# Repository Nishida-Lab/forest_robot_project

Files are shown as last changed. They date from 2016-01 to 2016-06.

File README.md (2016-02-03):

# Welcome to the forest_robot_project ! 

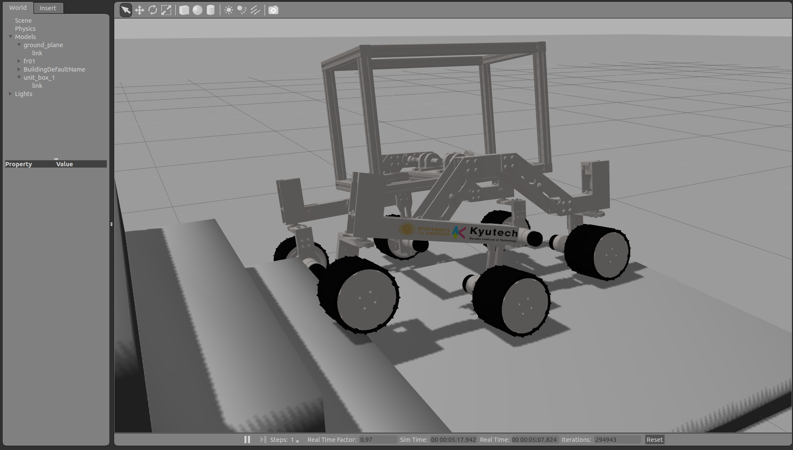
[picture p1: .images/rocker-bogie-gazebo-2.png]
fr01_gazebo


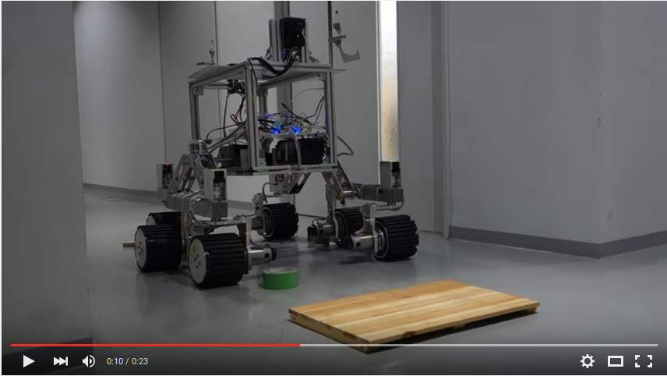
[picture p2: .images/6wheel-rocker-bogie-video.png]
fr01_real_machine (https://www.youtube.com/watch?v=MN6KCJ4qRo4)


### About
This is the repository for the forest robot (named FR01).  
**FR01** is created by [Nishida-Lab](http://lab.cntl.kyutech.ac.jp/~nishida/index.html) and [Ivan-Lab](https://www.ingegneria.unisalento.it/scheda_docente/-/people/ivan.giannoccaro).  
It has rocker-bogie mecanism. Basecally, We use [ROS](http://www.ros.org/) for control and integration.

### First of all
On this repository, there are some rules for developping.  
Please See [Issue #1](https://github.com/Nishida-Lab/forest_robot_project/issues/1) before starting.

### Install
See [Install wiki](https://github.com/Nishida-Lab/forest_robot_project/wiki/Installation-%5BEnglish%5D).

### Usage
See [Usage wiki](https://github.com/Nishida-Lab/forest_robot_project/wiki/Usage-%5BEnglish%5D).

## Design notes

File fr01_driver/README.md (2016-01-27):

# FR01(Forest Robot 01) driver

This package contains follow two nodes. 
- fr01_driver_node
- fr01_wheel_controller(not yet)

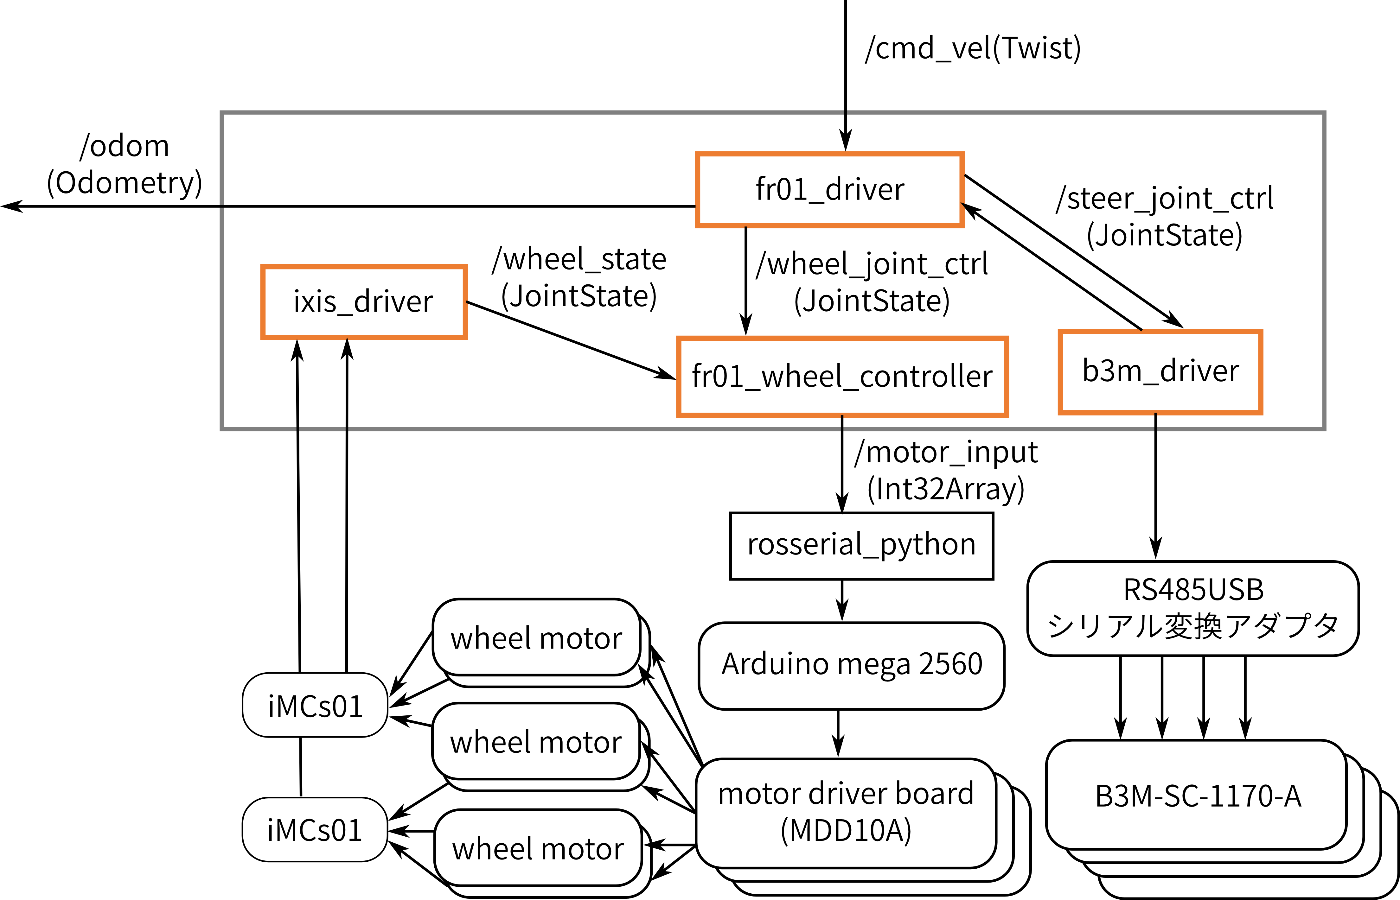
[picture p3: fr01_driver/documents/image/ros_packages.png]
ros_package
 

## fr01_driver_node
* subscribe
  - /cmd_vel
  - /wheel_state
  - /steer_state

* publish
  - /wheel_joint_ctrl
  - /steer_joint_ctrl
  - /odom

## fr01_wheel_controller_node
* subscribe
  - /wheel_state
  - /wheel_joint_ctrl

* publish
  - /motor_input(topic name is undecided)

## Preparation
In order to run this package, we need follow packages.
Please clone these packages manually or use wstool.

* [ros_ixis_imcs01_driver_beta](https://github.com/AriYu/ros_ixis_imcs01_driver_beta)
* [ros-kondo-b3m-driver-beta](https://github.com/AriYu/ros-kondo-b3m-driver-beta)

## How to run
Not yet.

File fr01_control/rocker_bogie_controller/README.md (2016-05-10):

## Rocker Bogie Controller ##

Controller for a rocker bogie drive mobile base.

Detailed user documentation can be found in the controller's [forest_robot_project wiki page](https://github.com/Nishida-Lab/forest_robot_project/wiki/rocker_bogie_controller).

- 左方向
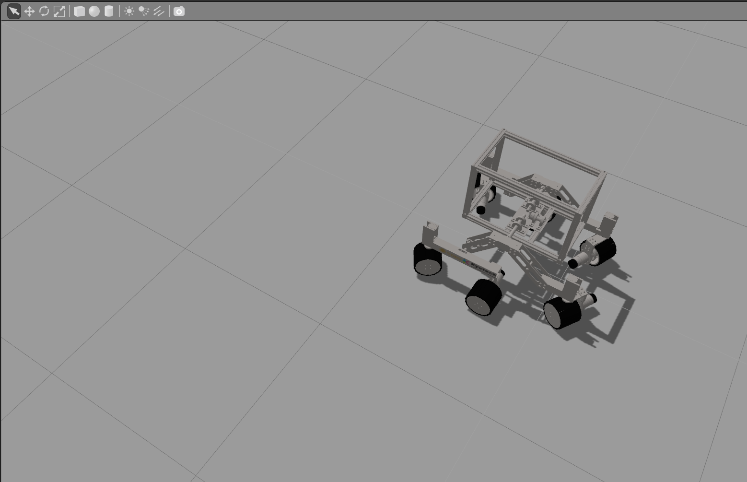
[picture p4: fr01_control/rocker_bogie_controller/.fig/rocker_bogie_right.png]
左方向


- 右方向
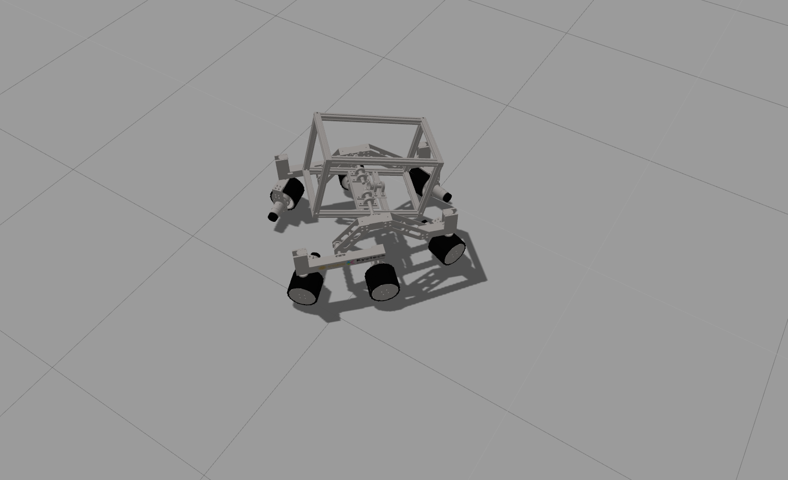
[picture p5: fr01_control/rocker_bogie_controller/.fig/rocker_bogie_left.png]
右方向


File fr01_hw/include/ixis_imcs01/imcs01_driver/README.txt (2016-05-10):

Linux kernel 3.2 用 iMCs01 USB ドライバ 2012年9月14日版
株式会社イクシスリサーチ

***ファイルについて***

Linux kernel 2.6 用 iMCs01 USB ドライバソース urbtc2.6ディレクトリ には以下のファ
イルが含まれています。

-imcs01_driver
  README.txt			//現在開いているファイル
  Makefile			//サンプルプログラム用Makefile
  h8test.c
  uread.c
  urobotc_ad.c
  urobotc_open_loop.c
  urobotm.c
  urobot_1ch_enc_pos.c
  urobot_enc_pos.c
─driver
    Makefile		//ビルド用の Makefile
    urbtc.c		//ドライバの本体
    urbtc.h		//ioctl 用のヘッダ
    urobotc.h		//read/write するデータを定義するヘッダ

***ビルドおよび動作環境***

Ubuntu1204で、ビルドおよび動作確認をしています。

ビルドには、uname -r でわかる現在動作中の kernel に対応する、
kernel-devel パッケージをインストールしておく必要があります。

$ uname -r
3.2.0-29-generic-pae

となるような環境では、linux-source-3.2.0 パッケージをあらかじめインストールしておいてください。
$ sudo apt-get install linux-source-3.2.0

カーネルソースをダウンロード後、以下を実施し、必要なファイル類の解凍を行います。
$ cd /usr/src
$ sudo tar xf linux-source-3.2.0.tar.bz2

/boot以下の現在のカーネル環境の.configを取得します。
$ cd linux-source-3.2.0
$ sudo cp /boot/confing-3.2.0-30-generic-pae .config

その後、makeを実施します。
$ sudo make oldconfig
$ sudo make

***ビルド方法***

ビルドはドライバのソースを展開したディレクトリに移動し、

$ make

とします。うまくコンパイルが成功するとドライバモジュールファイル
urbtc.ko が作成されます。

適切な kernel-devel パッケージがインストールされていない場合、以下の
ように表示されて make が失敗します。

$ make
make -C /lib/modules/2.6.15-1.2054_FC5/build M=/disk/tonki/d50/proj/ixs-usb/work/mrt/urbtc-2.6 modules
make: *** /lib/modules/2.6.15-1.2054_FC5/build: No such file or directory.  Stop.
make: *** [default] Error 2

***動作確認***

kernel 2.4 用ドライバのソースに附属の、以下のプログラムについて動作
確認しています。

h8test
uread
urobot_1ch_enc_pos
urobot_enc_pos
urobotc_ad
urobotc_open_loop
urobotm

環境は Ubuntu12.04です。

手順は
$ sudo insmod urbtc.ko
としてドライバをロードしたのちに、デバイスを USB コネクタに差します。

/dev/urbtc0が作られることを確認します。
$ ls -l /dev/urbtc*

アクセス権を変更します。
$ sudo chmod 777 /dev/urbtc0

上記のプログラムを順次起動しています。

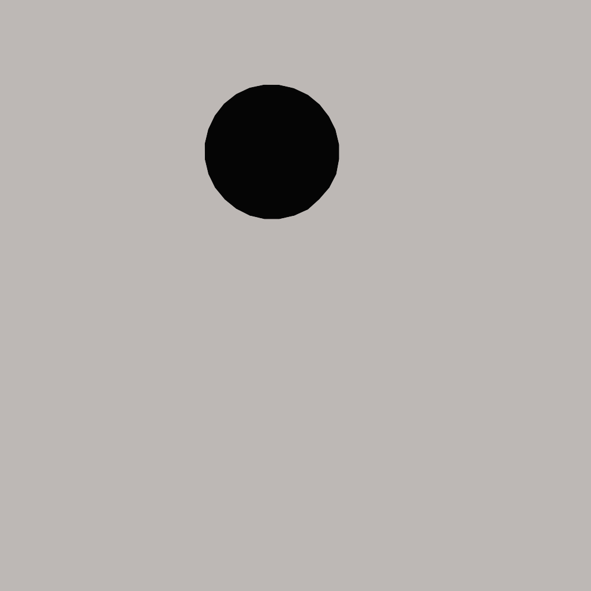
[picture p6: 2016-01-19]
fr01_description/meshes/visual/steer_link_texture.png

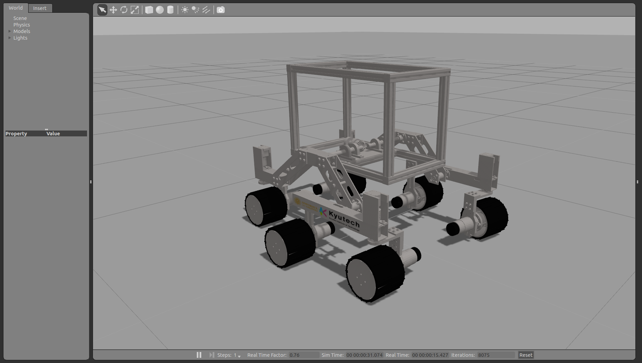
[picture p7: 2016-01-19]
.images/fr01_gazebo.png

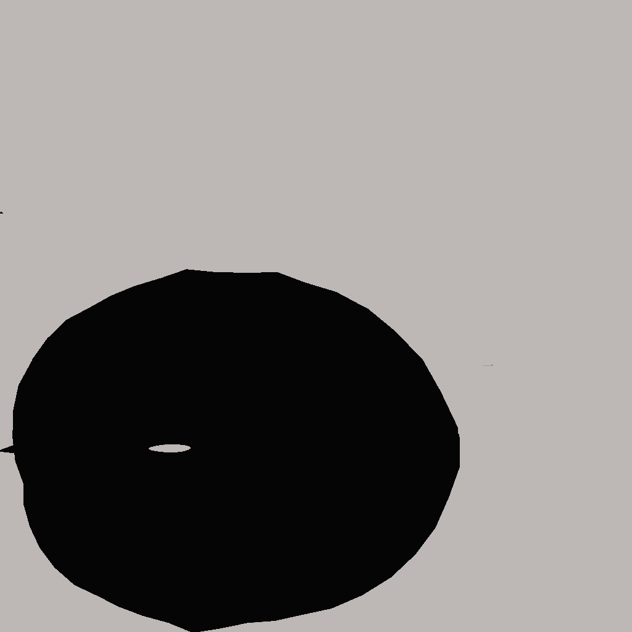
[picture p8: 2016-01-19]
fr01_description/meshes/visual/wheel_link_texture.png

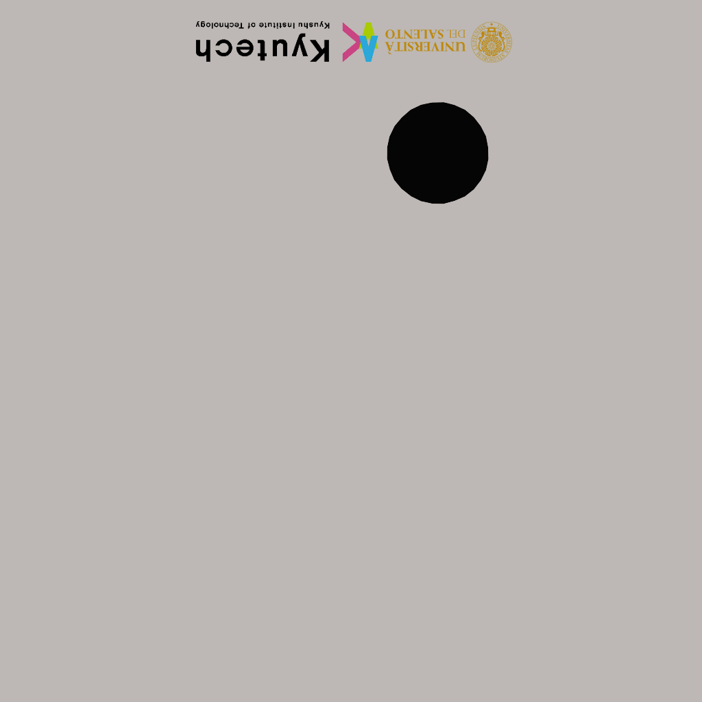
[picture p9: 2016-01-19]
fr01_description/meshes/visual/bogie_left_link_texture.png

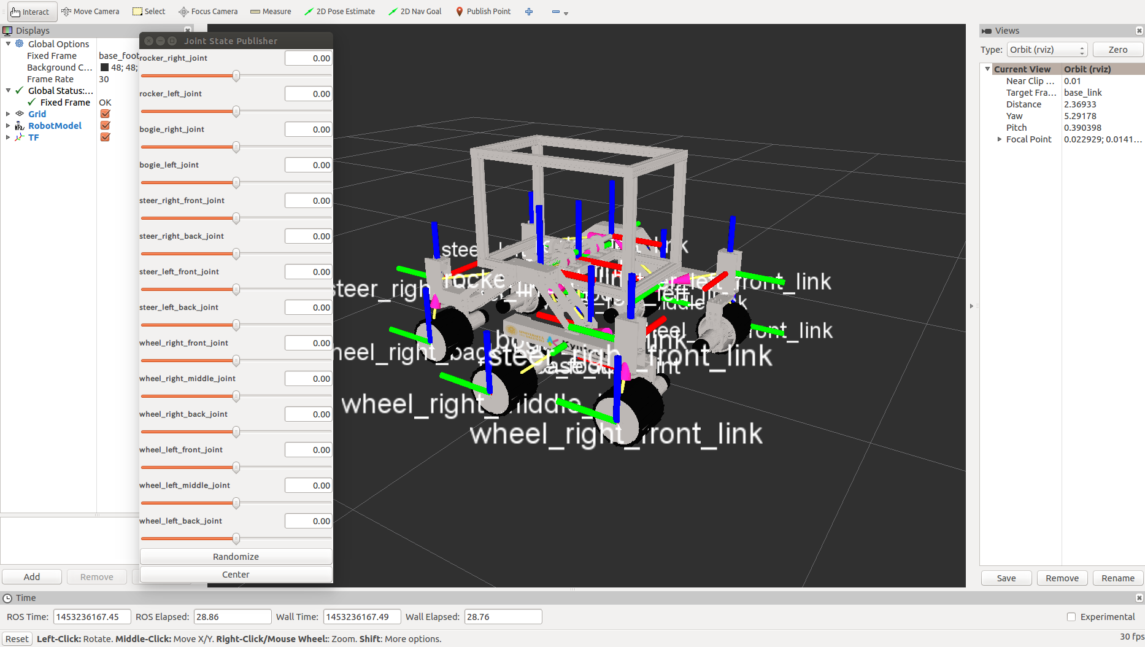
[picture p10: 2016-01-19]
.images/fr01_description_rviz.png

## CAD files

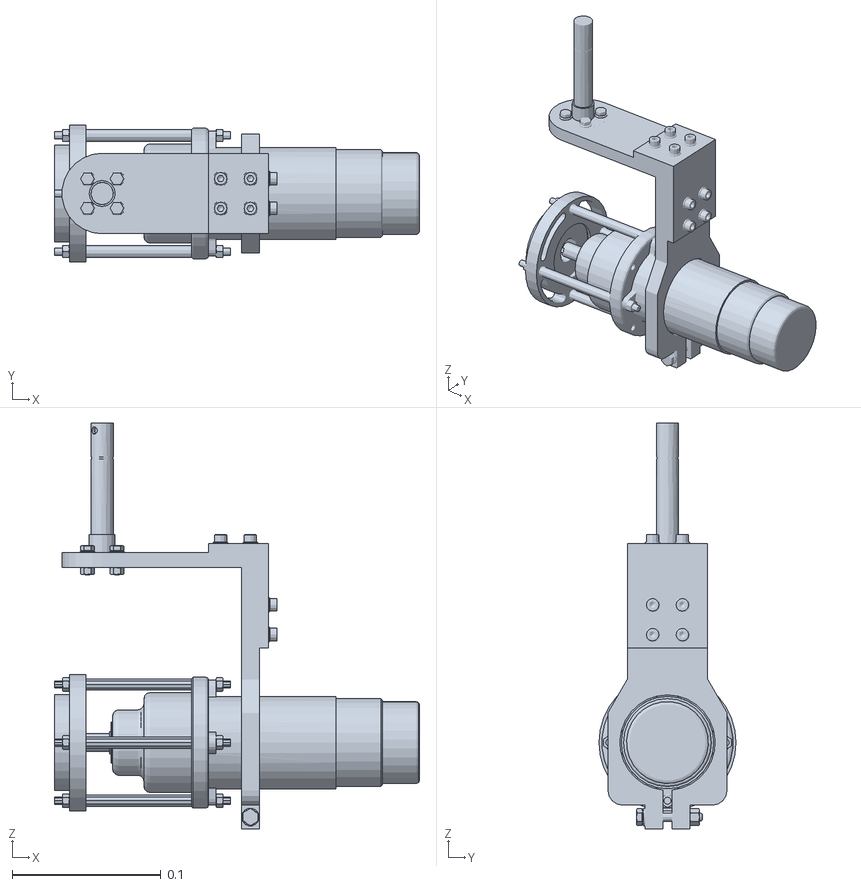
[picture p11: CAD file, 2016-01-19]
fr01_description/meshes/collision/steer_link.stl
0.245 x 0.092 x 0.273

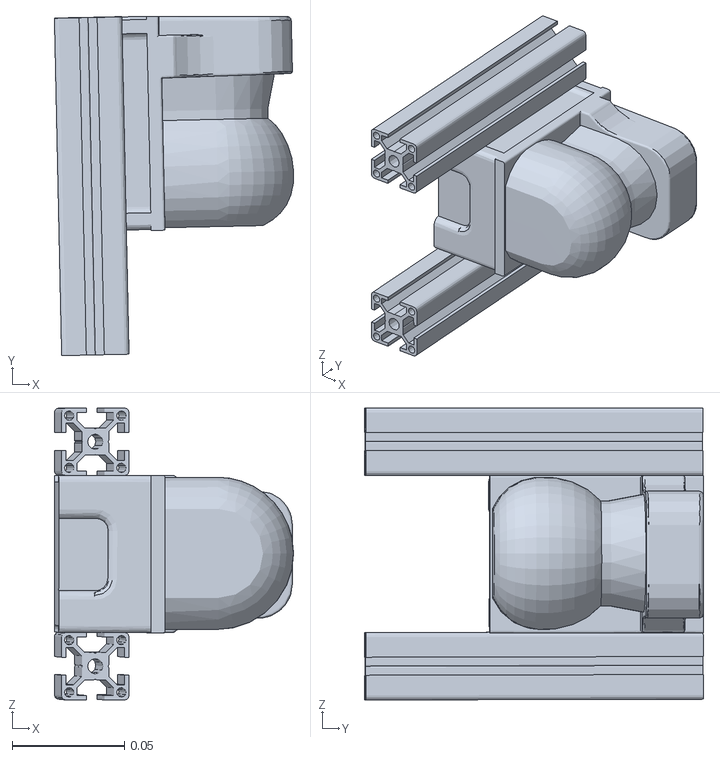
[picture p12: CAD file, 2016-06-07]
fr01_description/meshes/visual/yvt-x002.stl
0.106 x 0.151 x 0.13

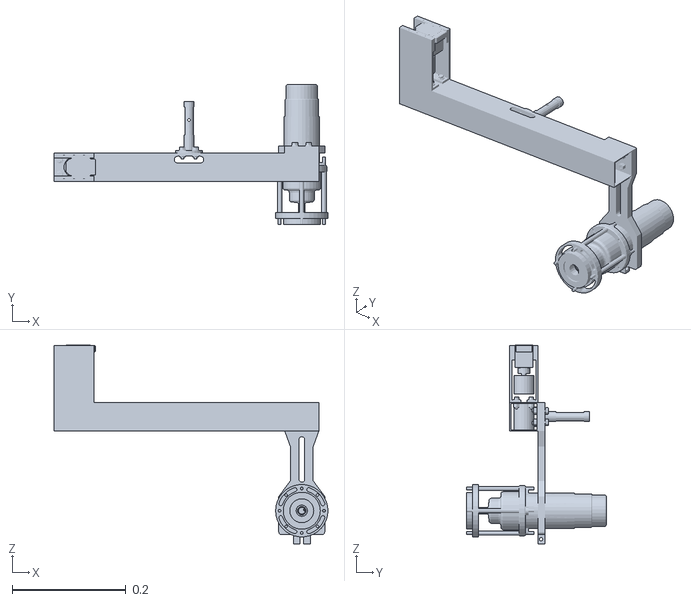
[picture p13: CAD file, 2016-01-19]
fr01_description/meshes/collision/bogie_left_link.stl
0.481 x 0.245 x 0.348

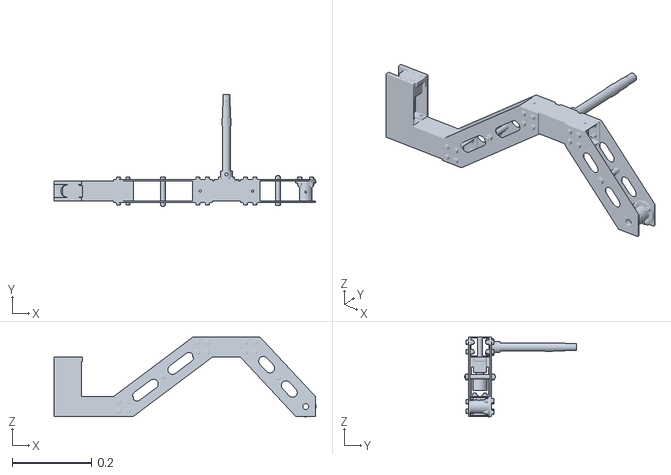
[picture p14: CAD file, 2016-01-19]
fr01_description/meshes/collision/rocker_right_link.stl
0.661 x 0.283 x 0.201

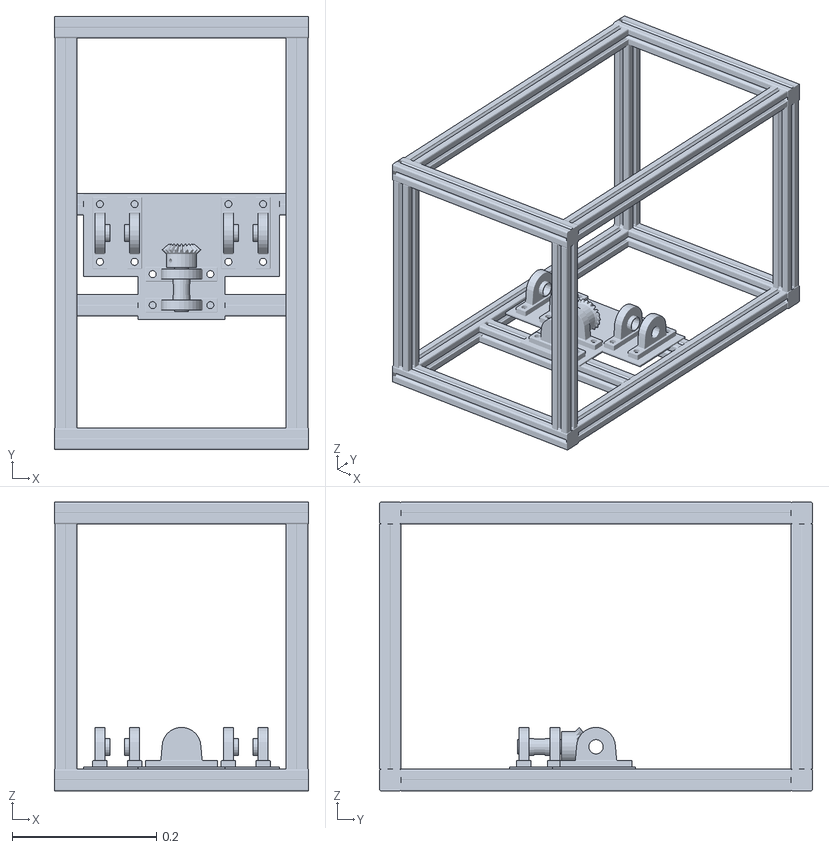
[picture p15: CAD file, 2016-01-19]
fr01_description/meshes/collision/base_link.stl
0.352 x 0.6 x 0.4

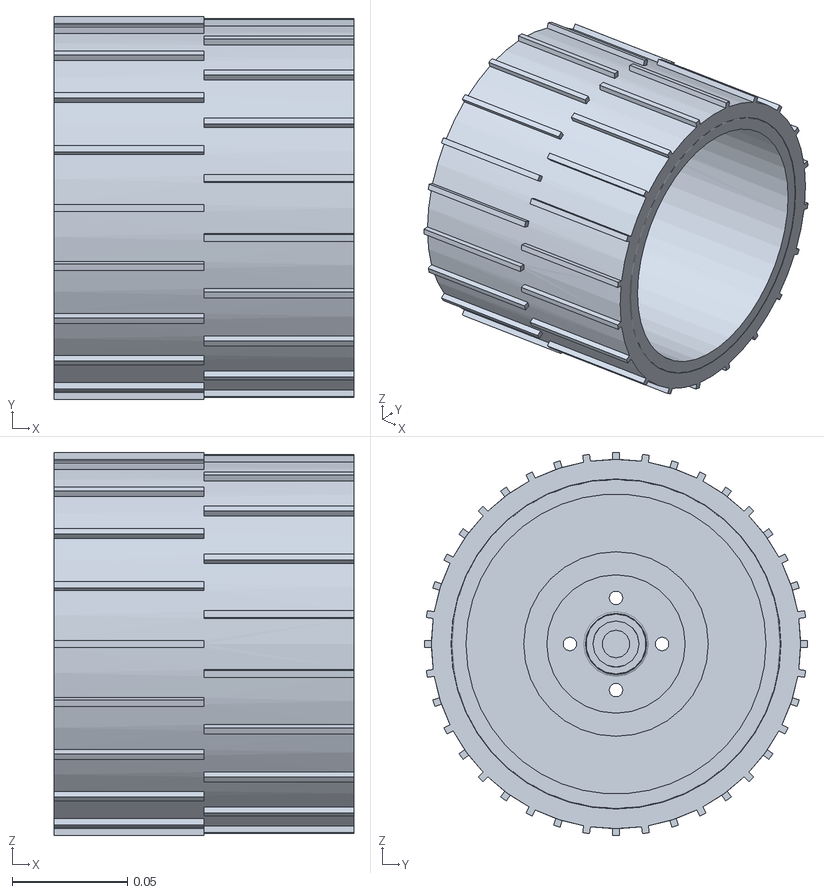
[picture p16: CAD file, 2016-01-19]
fr01_description/meshes/collision/wheel_link.stl
0.13 x 0.166 x 0.166

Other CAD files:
fr01_description/meshes/collision/rocker_left_link.stl
fr01_description/meshes/collision/bogie_right_link.stl

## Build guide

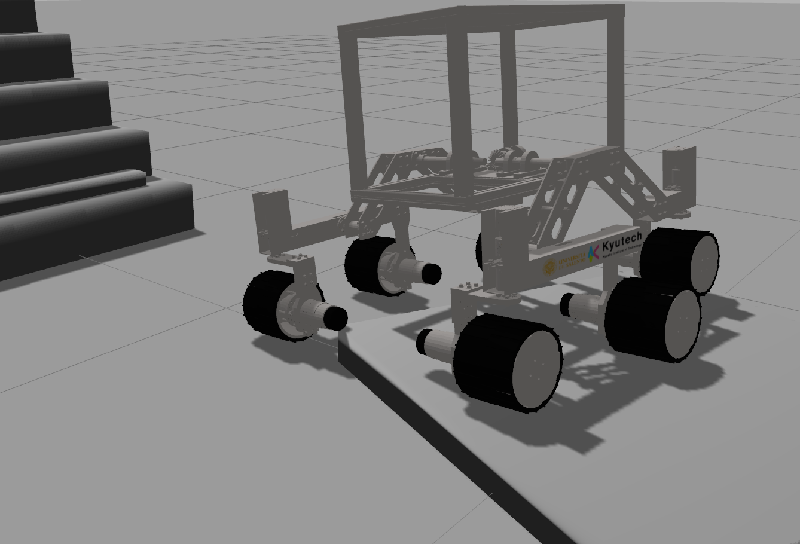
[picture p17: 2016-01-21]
.images/fr01_with_step_gazebo.png

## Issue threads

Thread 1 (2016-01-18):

About this repository

RyodoTanaka, 2016-01-18:
Nishida-Lab and Ivan-Lab members will share this repository.
So, We will set some rules.

1. If you commit and push your codes, please write the details about the modification.

2. If you have some question, ask at this issue page. Of course, in English please.

3. Please follow [GitHub-Flow](http://scottchacon.com/2011/08/31/github-flow.html) method.

Thanks for your understanding and cooperation.

P.S
Only first commit is written in Japanese. Please accept my apology....

---- From here for Japanese. ----
本リポジトリは、イタリアのサレント大学の方も閲覧するようになります。
なので、上記の通り、コミット履歴やissueなどは英語でおねがいします。
色々手間かと思いますが、何卒よろしくおねがいします。
P.S
最初のコミットだけ日本語になっています。ご容赦下さい。。。。

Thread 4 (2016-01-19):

About Gazebo Simulator

RyodoTanaka, 2016-01-19:
I already merged the codes for gazebo elements.
But there are some problems we have to resolve.
So, I want to share these info.And following info is same to #3 Pull Requests.

1. Now, steer and wheel joints are moved by joint position controller.
    We need to change this controller to velocity controller (We need to make original ros_controller).

2. Not enough at experiment. We need to experiment on steer, obstacle, and unevenness terrains.
    Of course, We need to create such terrains on Gazebo too.

3. Sometimes the calculation on Gazebo doesn't works.
    But now, I don't know the reason and solution.

That is all.
Thank you for your cooperation.

mum254, 2016-01-24:
@RyodoTanaka
> We need to change this controller to velocity controller (We need to make original ros_controller).

Do you really need to create a velocity controller from scratch?

[ros_control wiki](http://wiki.ros.org/ros_control) says the package also provides `velocity_controllers/joint_velocity_controllers` & `Joint Command Interfaces/Velocity Joint Interface`.

What about simply replacing the controller and the interface on `position` to the velocity ones?

RyodoTanaka, 2016-01-24:
@mum254
 > Do you really need to create a velocity controller from scratch?
 > ros_control wiki says the package also provides velocity_controllers/joint_velocity_controllers & Joint Command Interfaces/Velocity Joint Interface.
 > What about simply replacing the controller and the interface on Position to the Velocity ones?

Yes, Exactly. But I wanted to say that we need a velocity controller that the robot get the `cmd_vel` topic message ( that is `Twist` message I mean). So, I thought we need to calculate  the commands for each joints from  `cmd_vel` message.
And Now, we have a kinematics model and the matrix for calculation. So, I thought we need to create original controller...
Thank you for your advice and sorry for my less explanation.

mum254, 2016-01-24:
@RyodoTanaka
Ooops, excuse me. That makes sense! Surely you need original one =)

mum254, 2016-01-30:
@RyodoTanaka
May I try the controller stuff? I'm curious about both the kinematics and ros_control plugin implementation.

@luigicapodieci
I'll try to grasp basics on the paper you introduced to me =).
Let's have a discussion on my next visit (Feb.5).

RyodoTanaka, 2016-02-01:
@mum254
I'm sorry to late reply...

Sure, of course ! We need your help.
I have an interest in that and want to join your working.
Let's make it complete !!!

mum254, 2016-02-02:
@RyodoTanaka
Thanks!
Yeah. Let's make it together!

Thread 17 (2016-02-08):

About tf tree

AriYu, 2016-02-08:
I checked tf tree for adding `/odom` frame and found strange transforms like follow image.
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
I added `hokuyo3d_link` before checking tf tree.
I think `base_footprint` should be transformed from `base_link` or nearly root of tree.
Please tell me why it is, thank you.

RyodoTanaka, 2016-02-08:
@AriYu
Year, I understand your saying. And, I think It is not good (wrong) statement.
But there is a reason why I set such a strange tf tree. I'll tell you the situation.

First, I set the `base_footprint` be transformed from `base_link`.
Then, I simulated with Gazebo. And I found the `base_link` was moving. That means `base_footprint` was moving.
I thought `base_footprint` should be on the ground and not move (to Z axis direction).
So, I set these strange tf trees.

Of course I know it's not good idea, and may be I think, we don't need to do that.
But I have no idea. Please let me know your idea.

mum254, 2016-02-08:
I'm not familiar with the issue but let me give something here.

have a look at TF tree of p.310 of `Learning ROS for Robotics Programming 2nd Edition`. all related files about the tree are also available on Github including xacro of a very simple wheel robot.

hope u guys will find some hints from that.

AriYu, 2016-02-09:
@RyodoTanaka
OK, I understood.
But, why did you try to transform `base_footprint` from `base_link` ?
I read `Learning ROS for Robotics Programming 2nd Edition`,
the book say
`base_footprint` => `base_link` => `wheels`
is better.

@mum254
Thank you for your suggestion.

RyodoTanaka, 2016-02-09:
@AriYu
Sorry, I had mistake.
> First, I set the base_footprint be transformed from base_link.

That's not correct. I wanted to say
> I set the base_link be transformed from base_footprint.

I mean, I set the tree `base_footprint` -> `base_link`.
If you want to check that, go [72001a6bd18ebd8427af832ac2ffb376a0ec905f](https://github.com/Nishida-Lab/forest_robot_project/tree/72001a6bd18ebd8427af832ac2ffb376a0ec905f).
And on [the next commit (c9a5be3752d1d337ee8d7d0097c058869a3e1279)](https://github.com/Nishida-Lab/forest_robot_project/tree/c9a5be3752d1d337ee8d7d0097c058869a3e1279), I changed that to now we use.

RyodoTanaka, 2016-02-09:
@AriYu
Now, we don't use the gear on the middle of the robot. Because, we need more resource for calculation and the model would be more complex to simulate.
But, we have never tried that. And, we have another problem on the tf tree.
So now, It worth to add the gear on the simulated model I think.
Even if we need to recreate some stl files...
Please give me your opinion.

AriYu, 2016-02-09:
@RyodoTanaka
OK, I see.
For the time being, I will go under this structure of tf tree.
If we found better solution, fix this problem.
So, this issue will not close until this problem is solved.

AriYu, 2016-03-01:
In `fix-tf-tree` branch, we tried new structure of tf tree fr01.
A new structure of tf tree is like this.
`base_footprint` => `base_stabilized` => `base_link` => `other_links`
I referenced `hector_slam` tutorial. That link is [here](http://wiki.ros.org/hector_slam/Tutorials/SettingUpForYourRobot).
And, this structure looks no problems.
[fr01_modified_TF_tree.pdf](https://github.com/Nishida-Lab/forest_robot_project/files/152457/fr01_modified_TF_tree.pdf)
But, the modify will influence other programs such as using `fake_base_footprint`, because `fake_base_footprint` is deleted. Then, some other problems maybe occur.
So, I want to get your agreement.
Thank you @RyodoTanaka

Closed 2016-03-14.

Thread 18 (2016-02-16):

consultation about the implemention of  hardware_interface::RobotHW

AriYu, 2016-02-16:
I'm writing our original `hardware_interface` inheriting `hardware_interface::RobotHW` to adjust `ros_control`.
`fr01(forest robot)` has 6 wheel and 4 steer joints. And wheel is velocity control, steer is position control. But it look like that the `hardware_interface` class should be definite just only one. Then, the main function is like bellow snippet.
```
main()
{
  MyRobot robot;
  controller_manager::ControllerManager cm(&robot);

  while (true)
  {
     robot.read();
     cm.update(robot.get_time(), robot.get_period());
     robot.write();
     sleep();
  }
}
```
If we have to implement all in `read()` for all motors, the problem is `read()` require long time. Because, serial servo (B3M Kondo servo) is often mistake (invalid checksum) and we have to re-read from servo motor. In my experience, the maximum re-reading times is 4. Every reading require 5[ms].
As a result, above code snippet's loop rate maybe very slow.
How do I should do this ?

reference : https://github.com/ros-controls/ros_control/wiki/hardware_interface

mum254, 2016-02-16:
@AriYu
How do you handle the problem currently on the real robot?
I believe this is the common issue on both the current case and RobotHW case.

If `read()` method takes long time because of networking failure, it just cause that a constant command is sent to each actuators during `read()` method procedure.

In other words, a new command calculated from the newest value cannot be gained until `read()` returns.
Does this also happen in the current driver principle?

In the current driver, a command value from the newest joint position is computed when the topic `/wheel_state` is updated. Until then, a constant joint command should be sent to a motor driver.

This seems same with the procedure `cm.update()` is computed when the `read()` is finished. Until then, a constant joint command should be sent to a motor driver.

If I'm getting a mistake, please point it out. Thanks.

mum254, 2016-02-16:
I'll be in the lab on 2/17(Wed) in the morning. If you are available, please let me have a discussion on this.

AriYu, 2016-02-16:
@mum254
Sorry, I have class tomorrow morning from 8:50 until 10:20. But the other time, we can discuss. Thank you.

In the current structure of `fr01_driver`, steer control node and wheel control node is independent. So, wheel control node don't need to wait for steer control node updating. But, in `ros_control`, If we have to implement in `read()`(reading from wheel encoder and steer servo), wheel controller have to wait some times.

However , I came up with an idea just now. If we can publish some topic in `write()`, we use current node for wheel motor control. And `read()` taking long time wont be big problem.

AriYu, 2016-02-16:
@mum254
This is real robot implementation problem. Sorry, I forget to say that.

mum254, 2016-02-16:
@AriYu
ok, understood what you mean. talk about it later =-)

AriYu, 2016-02-24:
Now, ros_control for real hardware is implemented in `use_ros_control` branch.
And, almost of them are finished.
But, If you find some problem, please pull request.
The new rocker-bogie controller have developed, I will do test.

MoriKen254, 2016-02-24:
@AriYu
great! super quick job!
let me check the code & compatibility with gazebo=-)

MoriKen254, 2016-02-29:
@AriYu
Cool, I believe your code will be compatible with `ros_controller`. It's my turn to commit.

Now, let me check my understanding on your driver. Is the software configuration like the following fig? (some details are abbreviated.)
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
Please tell me a mistake if it exists.

By the way, when do you want the common `ros_controller` by? I might be short of developing time until next week. However, I wanna do my best to finish it by the deadline if you have.

AriYu, 2016-02-29:
@MoriKen254
Thanks.

I think that your understanding is right and the figure is awesome. Thank you your great works !!! Making the figure should be my work, sorry.

Please don't worry about deadline, because the interim presentation is April and the robot have moved already. Of cause, it is important to compatible with `ros_control` and I want to move the robot using `ros_control`. But it is not urgent.

Incidentally, I would like to move codes about `ros_control` to `fr01_control` directory from `fr01_driver` directory. How about this idea ?
And I want to remain `fr01_driver` directory, because `fr01_driver` is able to control real robot. However in the future, if we confirm to control the robot by using `ros_control`, I will remove it.

MoriKen254, 2016-03-01:
@AriYu
> don't worry about deadline

Ok, thanks.

>  I would like to move codes about ros_control to fr01_control directory from fr01_driver directory.

sure, I got it. I'll modify the configuration of fr01_control.

>  I want to remain fr01_driver directory

Ok, let's merge them after checking the compatibility. Thanks for your comment =-)

AriYu, 2016-03-02:
@MoriKen254
I have a question about `fr01_control` directory.
Where will I put code about `ros_control` for real hardware ?
For example
`fr01_control/src/real_hardware/some_codes_for_real_hardware.cpp`
or
`fr01_control/src/some_codes_real_hardware.cpp`
If you have any other idea, please tell me it.

MoriKen254, 2016-03-02:
@AriYu

I prefer the former one from your options.

Or how about the following one?
The main idea is to split hw space from controller one.
hw space includes real and sim hw codes, while control space includes ros_controller which is compatible with both real  and sim.

├ `fr01_control/` (ros_controller. both real and sim can use.)
│　├ `rocker_bogie_controller/`
│　│　└ src
│　│　　　└ rocker_bogie_controller.cpp
│　└ `some_another_custom_controller/`
│　　　└ src
│　　　　　└ some_another_custom_controller.cpp (not needed for now)
│
└ `fr01_hw/`
　　├ `real`
　　│　└ src/
　　│　　　├ hw_real_node.cpp
　　│　　　├ hw_real.cpp
　　│　　　└ some_codes_for_hw_real.cpp
　　└ `sim`
　　　　└ src/
　　　　　　└ codes_for_hw_sim_plugin.cpp (not needed for now)

Umm, what do you think about it? You wanna move driver codes to controller space don't you? I know your idea because `some_codes_for_hw_real` in fr01_driver also include `controller`.

In my opinion, dividing `RobotHW` and `ros_controller` seems reasonable.

If you have any idea about the issue, please let me know.

AriYu, 2016-03-03:
@MoriKen254
Thank you for your suggestion. I think your suggestion is very good.
I will try to organize directory structure following  your idea in `use_ros_control` branch.

Closed 2016-05-10.

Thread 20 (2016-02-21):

Please tell me wheel radius and width!

mum254, 2016-02-21:
As mentioned in the title. I couldn't figure them out from a collada format file lol.

## background
I'm trying to apply [diff_drive_controller](http://wiki.ros.org/diff_drive_controller) to the robot as start up.

The controller requires the radius and width of wheels, which are used to compute kinematics of the model inside and should be needed for our robot  model as well.

AriYu, 2016-02-21:
@mum254
I understood. That's great.
Wheel diameter is 0.16[m], so the radius is 0.08[m].
And width of wheels is 0.13[m].
If you want to get some other parameters, please feel free to ask anything.

mum254, 2016-02-22:
@AriYu
Thanks. I'll surely ask something again.

Closed 2016-02-22.

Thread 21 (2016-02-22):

Could you remove the namespace `fr01` from the urdf model?

mum254, 2016-02-22:
As mention in the title. If the request is accepted, I want you check all the compatibility about namespace other than the things I noted below. That's why I didn't send pull request directly.

That's because diff_drive_controller doesn't seem to support namespace so the original model with namespace doesn't response when it gets cmd_vel topic. Other robots on github using the controller don't seem to use namespace either I searched so far.

Thus firstly, I tried several approaches to keep namespace `fr01` while removing the namespace when applying diff_drive_controller. However, all of them didn't worked well to the extend I worked on.

The only and the simplest way is just removing the namespace from urdf. (To be honest, I don't wanna take looooong time to fix files to remain this namespace stuff lol.)

Then I change files as follows:

- removed `fr01` from control yaml file,
- removed `ns` property of `controller spawner` and <remap> tag of `robot_state_publisher` in fr01_sim_control.launch,
- removed <robotNamespace> tag from gazebo plugin load tag in fr01.urdf.xacro.

After that, gazebo model started to run with cmd_vel, and everything seems going well. If possible, please remove namespace like above and fix related items you guys know.

Thanks.

AriYu, 2016-02-23:
I see. It looks difficult to keep namespace `fr01`.
So, you can remove it and please pull request.
I think the gazebo model is independent other packages, so the effect is minimum. If there are some problem, I will fix it.

mum254, 2016-02-23:
@AriYu
Thanks. I'll push it later.
Let's implement the driver with a simple one at first and solve the namespace issue if another one gets needed =-)

AriYu, 2016-02-23:
@mum254
I see. Thanks.

mum254, 2016-02-23:
sent a request related on this issue. closing.

Closed 2016-02-23.

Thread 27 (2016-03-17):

Wheels somehow rotates undesirably

MoriKen254, 2016-03-17:
For now, I checked some behaviors on current drive controller as follows but haven't found any essential cause yet.

- on rocker_bogie
 - wheel joints somehow rotates even if set 0 command on every update timing.
 - consequently odom is updated undesirably.

- on diff_drive
 - Switching rocker_bogie_controller to diff_drive_controller doesn't solve the issue above.
 - this means the problem essentially occurs from diff_drive_controller or model.
 - in [jackal simulator](http://docs.ros.org/indigo/api/jackal_tutorials/html/simulation.html)(also using diff_drive), the same problem also happens but the effect is not so large.

If you have found something, please let me know.

Thanks.

AriYu, 2016-03-17:
@MoriKen254
Thank you your summery about problems on gazebo.
I want to check this problem on real robot, but now I haven't been able to move robot by using `ros_control`. There are some problems on `fr01_hw` pkg.
I will report the result on real robot if I success to control.

MoriKen254, 2016-03-17:
@AriYu
Thanks. I expect results on real robot because I doubt cause as follows.

- in gazebo, only three wheels looks being grounded(three point ground). three wheels may have gotten free joints.
- rotating wheels are 3 of 6 wheel: wheel_right_back, wheel_right_middle and wheel_left_middle.
- using diff_drive_controller with two wheels mond (only using wheel_left_front and wheel_right_front which does not rotate) looks solve the problem. effect seems very small like jackal simulator.

odomが勝手に更新される原因はこれのように思います．
ただ，上記をどう解決すればいいのか，まだ分かりません．

実ロボットなら少し浮いたところでjointが回っちゃうことはないと推測しています．
リアルロボットでの検証ができたら，教えて下さい．

取り急ぎ．

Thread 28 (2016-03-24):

wheel hardware interface looks not working well

AriYu, 2016-03-24:
I tried `rocker_bogie_controller` on real robot.
I add new `fr01_bringup` pkg for start up all necessary nodes, plugins and so on.
Then, I commanded following
```
roslaunch fr01_bringup fr01_bringup.launch
```
I succeeded  to control steering joints. But wheel joints had not moved.
I sought `ERROR` or `WARN` on screen messages and found following message
```
........
[ INFO] [1458821773.685239176]: id: 3
[ INFO] [1458821773.686747237]: Registered joint 'wheel_left_front_joint ' in the VelocityJointInterface
[ INFO] [1458821773.686843818]: Registered joint 'wheel_left_middle_joint ' in the VelocityJointInterface
[ INFO] [1458821773.686888245]: Registered joint 'wheel_left_back_joint ' in the VelocityJointInterface
[ INFO] [1458821773.686929655]: Registered joint 'wheel_right_front_joint ' in the VelocityJointInterface
[ INFO] [1458821773.686971095]: Registered joint 'wheel_right_middle_joint ' in the VelocityJointInterface
[ INFO] [1458821773.687012482]: Registered joint 'wheel_right_back_joint ' in the VelocityJointInterface
[ INFO] [1458821773.687055222]: Registered joint 'steer_left_front_joint ' in the PositionJointInterface
[ INFO] [1458821773.687094893]: Registered joint 'steer_left_back_joint ' in the PositionJointInterface
[ INFO] [1458821773.687133019]: Registered joint 'steer_right_front_joint ' in the PositionJointInterface
[ INFO] [1458821773.687175075]: Registered joint 'steer_right_back_joint ' in the PositionJointInterface
[ WARN] [1458821773.687236808]: Replacing previously registered interface 'hardware_interface::JointStateInterface'.
[ INFO] [1458821773.689524046]: joint_name: joint_2
[ INFO] [1458821773.694015663]: min_angle: -200
...........
```
So, they say `Replacing previously registered interface 'hardware_interface::JointStateInterface'.`.
I don't know why this is caused, but I suspect to need independent controller manager for every joint type. Now, velocity joint interface and position joint interface are into one `Robot::HW`.
Do you have any other ideas about cause of this problem ?

MoriKen254, 2016-03-24:
@AriYu
If you are using master or use_diff_drive_controller branch now, `forest_robot_project/fr01_control/launch/fr01_sim_control.launch` looks wrong.

Specifically, you don't need to spawn steer controller if rocker_bogie_controller is spawned.

```
    <!-- load the controllers -->
    <node name="controller_spawner" pkg="controller_manager"
        type="spawner" respawn="false"
        output="screen"
        args="fr01_diff_drive_controller
              joint_state_controller
              steer_right_front_joint_position_controller
              steer_right_back_joint_position_controller
              steer_left_front_joint_position_controller
              steer_left_back_joint_position_controller
              " />
```

See the launch file below in `add_fr01_rocker_bogie_controller`
https://github.com/Nishida-Lab/forest_robot_project/blob/add_fr01_rocker_bogie_controller/fr01_control/fr01_control/launch/fr01_sim_control.launch

Here is the right one.

```xml
    <node name="controller_spawner" pkg="controller_manager"
        type="spawner" respawn="false"
        output="screen"
        args="fr01_rocker_bogie_controller
        joint_state_controller
        " />
```

Maybe some configurations under `fr01_control` directory doesn't seem to inherit ones in `add_fr01_rocker_bogie_controller`, Please check it out and fix it.

Thanks.

AriYu, 2016-03-24:
@MoriKen254
Thank you for your comments.

Sorry, I forgot to notify using branch. The testing branch is `fix-fr01control-launch`.
I already had fixed `fr01_sim_control.launch` you pointed out.

Thank you.

MoriKen254, 2016-03-24:
@AriYu
Ok, excuse me.

Next, didn't you somehow register `joint_state_controller` twice?
Basically, 'hardware_interface::JointStateInterface` is only used in `joint_state_controller` and the console says the one is replaced.

AriYu, 2016-03-24:
@MoriKen254
I overlooked `hardware_interface::Joint **State** Interface`.
I will try to rewrite some codes.

Thank you !!

Closed 2016-05-10.

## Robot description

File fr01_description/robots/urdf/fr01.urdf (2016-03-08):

<?xml version="1.0" ?>
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
<robot name="fr01" xmlns:xacro="http://ros.org/wiki/xacro">
  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
  <link name="fake_base_footprint"/>
  <joint name="base_link_joint" type="fixed">
    <origin rpy="0 0 0" xyz="0 0 0.370"/>
    <parent link="fake_base_footprint"/>
    <child link="base_link"/>
  </joint>
  <link name="base_link">
    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
    <inertial>
      <mass value="6.441"/>
      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
    </inertial>
  </link>
  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
  <joint name="rocker_right_joint" type="revolute">
    <origin rpy="0 0 0" xyz="0 -0.213 0.028 "/>
    <parent link="base_link"/>
    <child link="rocker_right_link"/>
    <axis xyz="0 1 0"/>
    <dynamics dampint="0.7" friction="0.7"/>
    <limit effort="30.0" lower="-1.57079637" upper="1.57079637" velocity="6.28318548"/>
  </joint>
  <link name="rocker_right_link">
    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
    <inertial>
      <mass value="2.088"/>
      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
    </inertial>
  </link>
  <joint name="rocker_left_joint" type="revolute">
    <origin rpy="0 0 0" xyz="0 0.213 0.028 "/>
    <parent link="base_link"/>
    <child link="rocker_left_link"/>
    <axis xyz="0 1 0"/>
    <dynamics dampint="0.7" friction="0.7"/>
    <limit effort="30.0" lower="-1.57079637" upper="1.57079637" velocity="6.28318548"/>
  </joint>
  <link name="rocker_left_link">
    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
    <inertial>
      <mass value="2.088"/>
      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
    </inertial>
  </link>
  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
  <joint name="bogie_right_joint" type="revolute">
    <origin rpy="0 0 3.14159274" xyz="0.2 -0.019945 -0.15"/>
    <parent link="rocker_right_link"/>
    <child link="bogie_right_link"/>
    <axis xyz="0 1 0"/>
    <dynamics dampint="0.7" friction="0.7"/>
    <limit effort="30.0" lower="-1.57079637" upper="1.57079637" velocity="6.28318548"/>
  </joint>
  <link name="bogie_right_link">
    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
    <inertial>
      <mass value="3.374"/>
      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
    </inertial>
  </link>
  <joint name="bogie_left_joint" type="revolute">
    <origin rpy="0 0 3.14159274" xyz="0.2 0.019945 -0.15"/>
    <parent link="rocker_left_link"/>
    <child link="bogie_left_link"/>
    <axis xyz="0 1 0"/>
    <dynamics dampint="0.7" friction="0.7"/>
    <limit effort="30.0" lower="-1.57079637" upper="1.57079637" velocity="6.28318548"/>
  </joint>
  <link name="bogie_left_link">
    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
    <inertial>
      <mass value="3.374"/>
      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
    </inertial>
  </link>
  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
  <joint name="steer_right_front_joint" type="revolute">
    <origin rpy="0 0 -1.57079637" xyz="-0.202 0.115 0.05"/>
    <parent link="bogie_right_link"/>
    <child link="steer_right_front_link"/>
    <axis xyz="0 0 1"/>
    <dynamics dampint="0.7" friction="0.7"/>
    <limit effort="30.0" lower="-1.57079637" upper="1.57079637" velocity="6.28318548"/>
  </joint>
  <link name="steer_right_front_link">
    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
    <inertial>
      <mass value="2.522"/>
      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
    </inertial>
  </link>
  <joint name="steer_right_back_joint" type="revolute">
    <origin rpy="0 0 1.57079637" xyz="-0.4 -0.05 -0.1"/>
    <parent link="rocker_right_link"/>
    <child link="steer_right_back_link"/>
    <axis xyz="0 0 1"/>
    <dynamics dampint="0.7" friction="0.7"/>
    <limit effort="30.0" lower="-1.57079637" upper="1.57079637" velocity="6.28318548"/>
  </joint>
  <link name="steer_right_back_link">
    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
    <inertial>
      <mass value="2.522"/>
      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
    </inertial>
  </link>
  <joint name="steer_left_front_joint" type="revolute">
    <origin rpy="0 0 1.57079637" xyz="-0.202 -0.115 0.05"/>
    <parent link="bogie_left_link"/>
    <child link="steer_left_front_link"/>
    <axis xyz="0 0 1"/>
    <dynamics dampint="0.7" friction="0.7"/>
    <limit effort="30.0" lower="-1.57079637" upper="1.57079637" velocity="6.28318548"/>
  </joint>
  <link name="steer_left_front_link">
    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
    <inertial>
      <mass value="2.522"/>
      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
    </inertial>
  </link>
  <joint name="steer_left_back_joint" type="revolute">
    <origin rpy="0 0 -1.57079637" xyz="-0.4 0.05 -0.1"/>
    <parent link="rocker_left_link"/>
    <child link="steer_left_back_link"/>
    <axis xyz="0 0 1"/>
    <dynamics dampint="0.7" friction="0.7"/>
    <limit effort="30.0" lower="-1.57079637" upper="1.57079637" velocity="6.28318548"/>
  </joint>
  <link name="steer_left_back_link">
    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
    <inertial>
      <mass value="2.522"/>
      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
    </inertial>
  </link>
  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
  <joint name="wheel_right_front_joint" type="continuous">
    <origin rpy="0 0 0" xyz="-0.065 0 -0.2145"/>
    <parent link="steer_right_front_link"/>
    <child link="wheel_right_front_link"/>
    <axis xyz="1 0 0"/>
  </joint>
  <link name="wheel_right_front_link">
    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
    <inertial>
      <mass value="2.966"/>
      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
    </inertial>
  </link>
  <joint name="wheel_right_middle_joint" type="continuous">
    <origin rpy="0 0 -1.57079637" xyz="0.198 0.2485 -0.165"/>
    <parent link="bogie_right_link"/>
    <child link="wheel_right_middle_link"/>
    <axis xyz="1 0 0"/>
  </joint>
  <link name="wheel_right_middle_link">
    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
    <inertial>
      <mass value="2.966"/>
      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
    </inertial>
  </link>
  <joint name="wheel_right_back_joint" type="continuous">
    <origin rpy="0 0 0" xyz="-0.065 0 -0.2145"/>
    <parent link="steer_right_back_link"/>
    <child link="wheel_right_back_link"/>
    <axis xyz="1 0 0"/>
  </joint>
  <link name="wheel_right_back_link">
    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
    <inertial>
      <mass value="2.966"/>
      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
    </inertial>
  </link>
  <joint name="wheel_left_front_joint" type="continuous">
    <origin rpy="0 0 0" xyz="-0.065 0 -0.2145"/>
    <parent link="steer_left_front_link"/>
    <child link="wheel_left_front_link"/>
    <axis xyz="1 0 0"/>
  </joint>
  <link name="wheel_left_front_link">
    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
    <inertial>
      <mass value="2.966"/>
      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
    </inertial>
  </link>
  <joint name="wheel_left_middle_joint" type="continuous">
    <origin rpy="0 0 1.57079637" xyz="0.198 -0.2485 -0.165"/>
    <parent link="bogie_left_link"/>
    <child link="wheel_left_middle_link"/>
    <axis xyz="1 0 0"/>
  </joint>
  <link name="wheel_left_middle_link">
    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
    <inertial>
      <mass value="2.966"/>
      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
    </inertial>
  </link>
  <joint name="wheel_left_back_joint" type="continuous">
    <origin rpy="0 0 0" xyz="-0.065 0 -0.2145"/>
    <parent link="steer_left_back_link"/>
    <child link="wheel_left_back_link"/>
    <axis xyz="1 0 0"/>
  </joint>
  <link name="wheel_left_back_link">
    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
    <inertial>
      <mass value="2.966"/>
      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
    </inertial>
  </link>
  <link name="base_footprint"/>
  <joint name="base_footprint_joint" type="fixed">
    <origin rpy="0 0 0" xyz="0 0.213 -0.398"/>
    <parent link="rocker_right_link"/>
    <child link="base_footprint"/>
  </joint>
  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
  <xacro:body_gazebo_vo/>
  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
</robot>

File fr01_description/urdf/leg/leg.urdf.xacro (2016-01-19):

<?xml version="1.0"?>
<robot xmlns:xacro="http://ros.org/wiki/xacro">

  <xacro:include filename="$(find fr01_description)/urdf/leg/leg.gazebo.xacro"/>
  <xacro:include filename="$(find fr01_description)/urdf/leg/leg.transmission.xacro"/>
  
  <xacro:macro name="bogie_v0" params="side parent *link_origin *inertia *joint_origin *joint_axis">
	<joint name="bogie_${side}_joint" type="revolute">
	  <insert_block name="joint_origin"/>
	  <parent link="${parent}"/>
	  <child link="bogie_${side}_link"/>
	  <insert_block name="joint_axis"/>
	  <dynamics dampint="0.7" friction="0.7"/>
	  <limit effort="30.0" lower="${-M_PI/2}" upper="${M_PI/2}" velocity="${2*M_PI}"/>
	</joint>
	
    <link name="bogie_${side}_link">
      <visual>
		<insert_block name="link_origin"/>
        <geometry>
          <mesh filename="package://fr01_description/meshes/visual/bogie_${side}_link.dae"/>
        </geometry>
      </visual>
      <collision>
		<insert_block name="link_origin"/>
        <geometry>
		  <mesh filename="package://fr01_description/meshes/collision/bogie_${side}_link.stl"/>
        </geometry>
      </collision>
      <inertial>
		<mass value="3.374"/>		
		<insert_block name="inertia"/>
      </inertial>
    </link>
  </xacro:macro>

  <xacro:macro name="rocker_v0" params="side parent *link_origin *inertia *joint_origin *joint_axis">
	<joint name="rocker_${side}_joint" type="revolute">
	  <insert_block name="joint_origin"/>
	  <parent link="${parent}"/>
	  <child link="rocker_${side}_link"/>
	  <insert_block name="joint_axis"/>
	  <dynamics dampint="0.7" friction="0.7"/>
	  <limit effort="30.0" lower="${-M_PI/2}" upper="${M_PI/2}" velocity="${2*M_PI}"/>
	</joint>
	
	<link name="rocker_${side}_link">
	  <visual>
		<insert_block name="link_origin"/>
        <geometry>
          <mesh filename="package://fr01_description/meshes/visual/rocker_${side}_link.dae"/>
        </geometry>
      </visual>
      <collision>
		<insert_block name="link_origin"/>
        <geometry>
		  <mesh filename="package://fr01_description/meshes/collision/rocker_${side}_link.stl"/>
        </geometry>
      </collision>
      <inertial>
		<mass value="2.088"/>
		<insert_block name="inertia"/>
      </inertial>
    </link>
  </xacro:macro>
  
</robot>

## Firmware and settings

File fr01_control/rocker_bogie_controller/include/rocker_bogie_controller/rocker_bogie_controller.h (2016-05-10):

/*********************************************************************
 * Software License Agreement (BSD License)
 *
 *  Copyright (c) 2013, PAL Robotics, S.L.
 *  All rights reserved.
 *
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
 *   * Redistributions of source code must retain the above copyright
 *     notice, this list of conditions and the following disclaimer.
 *   * Redistributions in binary form must reproduce the above
 *     copyright notice, this list of conditions and the following
 *     disclaimer in the documentation and/or other materials provided
 *     with the distribution.
 *   * Neither the name of the PAL Robotics nor the names of its
 *     contributors may be used to endorse or promote products derived
 *     from this software without specific prior written permission.
 *
 *  THIS SOFTWARE IS PROVIDED BY THE COPYRIGHT HOLDERS AND CONTRIBUTORS
 *  "AS IS" AND ANY EXPRESS OR IMPLIED WARRANTIES, INCLUDING, BUT NOT
 *  LIMITED TO, THE IMPLIED WARRANTIES OF MERCHANTABILITY AND FITNESS
 *  FOR A PARTICULAR PURPOSE ARE DISCLAIMED. IN NO EVENT SHALL THE
 *  COPYRIGHT OWNER OR CONTRIBUTORS BE LIABLE FOR ANY DIRECT, INDIRECT,
 *  INCIDENTAL, SPECIAL, EXEMPLARY, OR CONSEQUENTIAL DAMAGES (INCLUDING,
 *  BUT NOT LIMITED TO, PROCUREMENT OF SUBSTITUTE GOODS OR SERVICES;
 *  LOSS OF USE, DATA, OR PROFITS; OR BUSINESS INTERRUPTION) HOWEVER
 *  CAUSED AND ON ANY THEORY OF LIABILITY, WHETHER IN CONTRACT, STRICT
 *  LIABILITY, OR TORT (INCLUDING NEGLIGENCE OR OTHERWISE) ARISING IN
 *  ANY WAY OUT OF THE USE OF THIS SOFTWARE, EVEN IF ADVISED OF THE
 *  POSSIBILITY OF SUCH DAMAGE.
 *********************************************************************/

/*
 * Author: Enrique Fernández
 */

#include <controller_interface/controller.h>
#include <hardware_interface/joint_command_interface.h>
#include <pluginlib/class_list_macros.h>

#include <nav_msgs/Odometry.h>
#include <tf/tfMessage.h>

#include <realtime_tools/realtime_buffer.h>
#include <realtime_tools/realtime_publisher.h>

#include <rocker_bogie_controller/odometry.h>
#include <rocker_bogie_controller/speed_limiter.h>
#include <rocker_bogie_controller/multi_interface_controller.h>

namespace rocker_bogie_controller{

  /**
   * This class makes some assumptions on the model of the robot:
   *  - the rotation axes of wheels are collinear
   *  - the wheels are identical in radius
   * Additional assumptions to not duplicate information readily available in the URDF:
   *  - the wheels have the same parent frame
   *  - a wheel collision geometry is a cylinder in the urdf
   *  - a wheel joint frame center's vertical projection on the floor must lie within the contact patch
   */
  class RockerBogieController
      : public controller_interface::MultiInterfaceController<
      hardware_interface::PositionJointInterface,
      hardware_interface::VelocityJointInterface>
  {
    // constants
  private:
    enum INDX_WHEEL {
      INDX_WHEEL_FRNT = 0,
      INDX_WHEEL_MID = 1,
      INDX_WHEEL_BACK = 2,
    };
    enum INDX_STEER {
      INDX_STEER_FRNT = 0,
      INDX_STEER_BACK = 1,
    };

  public:
    RockerBogieController();

    /**
     * \brief Initialize controller
     * \param hw            Velocity joint interface for the wheels
     * \param root_nh       Node handle at root namespace
     * \param controller_nh Node handle inside the controller namespace
     */
    bool init(//hardware_interface::VelocityJointInterface *hw,
              hardware_interface::RobotHW* robot_hw,
              ros::NodeHandle& root_nh,
              ros::NodeHandle &controller_nh);

    /**
     * \brief Updates controller, i.e. computes the odometry and sets the new velocity commands
     * \param time   Current time
     * \param period Time since the last called to update
     */
    void update(const ros::Time& time, const ros::Duration& period);

    /**
     * \brief Starts controller
     * \param time Current time
     */
    void starting(const ros::Time& time);

    /**
     * \brief Stops controller
     * \param time Current time
     */
    void stopping(const ros::Time& /*time*/);

  private:
    std::string name_;

    /// Odometry related:
    ros::Duration publish_period_;
    ros::Time last_state_publish_time_;
    bool open_loop_;

    /// Hardware handles:
    std::vector<hardware_interface::JointHandle> left_wheel_joints_;
    std::vector<hardware_interface::JointHandle> right_wheel_joints_;
    std::vector<hardware_interface::JointHandle> left_steer_joints_;
    std::vector<hardware_interface::JointHandle> right_steer_joints_;

    /// Velocity command related:
    struct Commands
    {
      double lin;
      double ang;
      ros::Time stamp;

      Commands() : lin(0.0), ang(0.0), stamp(0.0) {}
    };
    realtime_tools::RealtimeBuffer<Commands> command_;
    Commands command_struct_;
    ros::Subscriber sub_command_;

    /// Odometry related:
    boost::shared_ptr<realtime_tools::RealtimePublisher<nav_msgs::Odometry> > odom_pub_;
    boost::shared_ptr<realtime_tools::RealtimePublisher<tf::tfMessage> > tf_odom_pub_;
    Odometry odometry_;

    /// Wheel separation, wrt the midpoint of the wheel width:
    double wheel_separation_w_;

    /// Wheel separation, wrt the midpoint of the wheel width:
    double wheel_separation_h_;

    /// Wheel radius (assuming it's the same for the left and right wheels):
    double wheel_radius_;

    /// Wheel separation and radius calibration multipliers:
    double wheel_separation_multiplier_;
    double wheel_radius_multiplier_;

    /// Timeout to consider cmd_vel commands old:
    double cmd_vel_timeout_;

    /// Whether to allow multiple publishers on cmd_vel topic or not:
    bool allow_multiple_cmd_vel_publishers_;

    /// Frame to use for the robot base:
    std::string base_frame_id_;

    /// Frame to use for odometry and odom tf:
    std::string odom_frame_id_;

    /// Whether to publish odometry to tf or not:
    bool enable_odom_tf_;

    /// Number of wheel joints:
    size_t wheel_joints_size_;

    /// Number of steer joints:
    size_t steer_joints_size_;

    /// Speed limiters:
    Commands last1_cmd_;
    Commands last0_cmd_;
    SpeedLimiter limiter_lin_;
    SpeedLimiter limiter_ang_;

    // FOR_DEBUG
    std::string ns_;
//#define GUI_DEBUG // uncommentout when you use qtcreator for debugging
#ifdef GUI_DEBUG
    bool isCmdVelImput_;
#endif

  private:
    /**
     * \brief Brakes the wheels, i.e. sets the velocity to 0
     */
    void brake();

    /**
     * \brief Velocity command callback
     * \param command Velocity command message (twist)
     */
    void cmdVelCallback(const geometry_msgs::Twist& command);

    /**
     * \brief Get the wheel names from a wheel param
     * \param [in]  controller_nh Controller node handler
     * \param [in]  wheel_param   Param name
     * \param [out] wheel_names   Vector with the whel names
     * \return true if the wheel_param is available and the wheel_names are
     *        retrieved successfully from the param server; false otherwise
     */
    bool getWheelNames(ros::NodeHandle& controller_nh,
                       const std::string& wheel_param,
                       std::vector<std::string>& wheel_names);

    /**
     * \brief Get the steer names from a steer param
     * \param [in]  controller_nh Controller node handler
     * \param [in]  steer_param   Param name
     * \param [out] steer_names   Vector with the steer names
     * \return true if the steer_param is available and the steer_names are
     *        retrieved successfully from the param server; false otherwise
     */
    bool getSteerNames(ros::NodeHandle& controller_nh,
                       const std::string& steer_param,
                       std::vector<std::string>& steer_names);

    /**
     * \brief Sets odometry parameters from the URDF, i.e. the wheel radius and separation
     * \param root_nh Root node handle
     * \param left_wheel_name Name of the left wheel joint
     * \param right_wheel_name Name of the right wheel joint
     */
    bool setOdomParamsFromUrdf(ros::NodeHandle& root_nh,
                               const std::string& left_wheel_name,
                               const std::string& right_wheel_name,
                               bool lookup_wheel_separation,
                               bool lookup_wheel_radius);

    /**
     * \brief Sets the odometry publishing fields
     * \param root_nh Root node handle
     * \param controller_nh Node handle inside the controller namespace
     */
    void setOdomPubFields(ros::NodeHandle& root_nh, ros::NodeHandle& controller_nh);

  };

  PLUGINLIB_EXPORT_CLASS(rocker_bogie_controller::RockerBogieController, controller_interface::ControllerBase);
} // namespace diff_drive_controller

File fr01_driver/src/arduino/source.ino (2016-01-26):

#include <ros.h> // Use ros_lib.
#include <std_msgs/Int32.h>
#include <std_msgs/Int32MultiArray.h>
#include <sensor_msgs/JointState.h>

#define num_of_motor 6
#define MIN_PWM -100
#define MAX_PWM 100

int dir_pin_array[num_of_motor] = {27, 26, 23, 22, 25, 24};
int pwm_pin_array[num_of_motor] = { 4,  5,  8,  9,  6,  7};

bool rotate_positive[num_of_motor] = {HIGH, LOW, HIGH, LOW, HIGH, LOW};
bool rotate_negative[num_of_motor] = {LOW, HIGH, LOW, HIGH, LOW, HIGH};


/* Declare proto type functions. */
void wheelCb(const std_msgs::Int32MultiArray& msg); 

/* Declare global variables. */
ros::NodeHandle nh; // The nodeHandle.
ros::Subscriber<std_msgs::Int32MultiArray> sub("/motor_input", &wheelCb); // Set subscribe the motor_driver topic.

void setup() {
  /* Set pins Mode. */
  for (int i = 0; i < 6; ++i) {
      pinMode(dir_pin_array[i], OUTPUT);
      pinMode(pwm_pin_array[i], OUTPUT);
  }
  /* Node handle setting. */
  nh.initNode(); // First setup the node handle.
  nh.subscribe(sub); // Start subscribe the "steer_ctrl" topic.
}

void loop() {
  nh.spinOnce(); // Check topic and if change it, run the call back function.
}


void wheelCb(const std_msgs::Int32MultiArray& msg) {
  for(int i = 0; i < num_of_motor; ++i)
  {
    if(msg.data[i] >= 0)
    {
      digitalWrite(dir_pin_array[i], rotate_positive[i]);
      if(msg.data[i] > MAX_PWM)
      {
        msg.data[i] = MAX_PWM;
      }
      analogWrite(pwm_pin_array[i], fabs(msg.data[i]));
    }
    else
    {
      digitalWrite(dir_pin_array[i], rotate_negative[i]);
      if(msg.data[i] < MIN_PWM)
      {
        msg.data[i] = MIN_PWM;
      }
      analogWrite(pwm_pin_array[i], fabs(msg.data[i]));
      //analogWrite(pwm_pin_array[i], 80);
    }
  }
}

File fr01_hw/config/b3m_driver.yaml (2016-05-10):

joint_0_driver:
  joint_name: joint_0
  id: 2
  min_angle: -50
  max_angle: 200

joint_1_driver:
  joint_name: joint_1
  id: 0
  min_angle: -200
  max_angle: 60

joint_2_driver:
  joint_name: joint_2
  id: 3
  min_angle: -200
  max_angle: 50

joint_3_driver:
  joint_name: joint_3
  id: 1
  min_angle: -50
  max_angle: 200

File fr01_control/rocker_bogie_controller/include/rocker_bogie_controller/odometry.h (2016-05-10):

/*********************************************************************
 * Software License Agreement (BSD License)
 *
 *  Copyright (c) 2013, PAL Robotics, S.L.
 *  All rights reserved.
 *
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
 *   * Redistributions of source code must retain the above copyright
 *     notice, this list of conditions and the following disclaimer.
 *   * Redistributions in binary form must reproduce the above
 *     copyright notice, this list of conditions and the following
 *     disclaimer in the documentation and/or other materials provided
 *     with the distribution.
 *   * Neither the name of the PAL Robotics nor the names of its
 *     contributors may be used to endorse or promote products derived
 *     from this software without specific prior written permission.
 *
 *  THIS SOFTWARE IS PROVIDED BY THE COPYRIGHT HOLDERS AND CONTRIBUTORS
 *  "AS IS" AND ANY EXPRESS OR IMPLIED WARRANTIES, INCLUDING, BUT NOT
 *  LIMITED TO, THE IMPLIED WARRANTIES OF MERCHANTABILITY AND FITNESS
 *  FOR A PARTICULAR PURPOSE ARE DISCLAIMED. IN NO EVENT SHALL THE
 *  COPYRIGHT OWNER OR CONTRIBUTORS BE LIABLE FOR ANY DIRECT, INDIRECT,
 *  INCIDENTAL, SPECIAL, EXEMPLARY, OR CONSEQUENTIAL DAMAGES (INCLUDING,
 *  BUT NOT LIMITED TO, PROCUREMENT OF SUBSTITUTE GOODS OR SERVICES;
 *  LOSS OF USE, DATA, OR PROFITS; OR BUSINESS INTERRUPTION) HOWEVER
 *  CAUSED AND ON ANY THEORY OF LIABILITY, WHETHER IN CONTRACT, STRICT
 *  LIABILITY, OR TORT (INCLUDING NEGLIGENCE OR OTHERWISE) ARISING IN
 *  ANY WAY OUT OF THE USE OF THIS SOFTWARE, EVEN IF ADVISED OF THE
 *  POSSIBILITY OF SUCH DAMAGE.
 *********************************************************************/

/*
 * Author: Luca Marchionni
 * Author: Bence Magyar
 * Author: Enrique Fernández
 * Author: Paul Mathieu
 */

#ifndef ODOMETRY_H_
#define ODOMETRY_H_

#include <ros/time.h>
#include <boost/accumulators/accumulators.hpp>
#include <boost/accumulators/statistics/stats.hpp>
#include <boost/accumulators/statistics/rolling_mean.hpp>
#include <boost/function.hpp>

namespace rocker_bogie_controller
{
  namespace bacc = boost::accumulators;

  /**
   * \brief The Odometry class handles odometry readings
   * (2D pose and velocity with related timestamp)
   */
  class Odometry
  {
  public:

    /// Integration function, used to integrate the odometry:
    typedef boost::function<void(double, double)> IntegrationFunction;

    /**
     * \brief Constructor
     * Timestamp will get the current time value
     * Value will be set to zero
     * \param velocity_rolling_window_size Rolling window size used to compute the velocity mean
     */
    Odometry(size_t velocity_rolling_window_size = 10);

    /**
     * \brief Initialize the odometry
     * \param time Current time
     */
    void init(const ros::Time &time);

    /**
     * \brief Updates the odometry class with latest wheels position
     * \param left_pos  Left  wheel position [rad]
     * \param right_pos Right wheel position [rad]
     * \param time      Current time
     * \return true if the odometry is actually updated
     */
    bool update(double left_pos, double right_pos, const ros::Time &time);

    /**
     * \brief Updates the odometry class with latest velocity command
     * \param linear  Linear velocity [m/s]
     * \param angular Angular velocity [rad/s]
     * \param time    Current time
     */
    void updateOpenLoop(double linear, double angular, const ros::Time &time);

    /**
     * \brief heading getter
     * \return heading [rad]
     */
    double getHeading() const
    {
      return heading_;
    }

    /**
     * \brief x position getter
     * \return x position [m]
     */
    double getX() const
    {
      return x_;
    }

    /**
     * \brief y position getter
     * \return y position [m]
     */
    double getY() const
    {
      return y_;
    }

    /**
     * \brief linear velocity getter
     * \return linear velocity [m/s]
     */
    double getLinear() const
    {
      return linear_;
    }

    /**
     * \brief angular velocity getter
     * \return angular velocity [rad/s]
     */
    double getAngular() const
    {
      return angular_;
    }

    /**
     * \brief Sets the wheel parameters: radius and separation
     * \param wheel_separation Seperation between left and right wheels [m]
     * \param wheel_radius     Wheel radius [m]
     */
    void setWheelParams(double wheel_separation, double wheel_radius);

    /**
     * \brief Velocity rolling window size setter
     * \param velocity_rolling_window_size Velocity rolling window size
     */
    void setVelocityRollingWindowSize(size_t velocity_rolling_window_size);

  private:

    /// Rolling mean accumulator and window:
    typedef bacc::accumulator_set<double, bacc::stats<bacc::tag::rolling_mean> > RollingMeanAcc;
    typedef bacc::tag::rolling_window RollingWindow;

    /**
     * \brief Integrates the velocities (linear and angular) using 2nd order Runge-Kutta
     * \param linear  Linear  velocity   [m] (linear  displacement, i.e. m/s * dt) computed by encoders
     * \param angular Angular velocity [rad] (angular displacement, i.e. m/s * dt) computed by encoders
     */
    void integrateRungeKutta2(double linear, double angular);

    /**
     * \brief Integrates the velocities (linear and angular) using exact method
     * \param linear  Linear  velocity   [m] (linear  displacement, i.e. m/s * dt) computed by encoders
     * \param angular Angular velocity [rad] (angular displacement, i.e. m/s * dt) computed by encoders
     */
    void integrateExact(double linear, double angular);

    /**
     *  \brief Reset linear and angular accumulators
     */
    void resetAccumulators();

    /// Current timestamp:
    ros::Time timestamp_;

    /// Current pose:
    double x_;        //   [m]
    double y_;        //   [m]
    double heading_;  // [rad]

    /// Current velocity:
    double linear_;  //   [m/s]
    double angular_; // [rad/s]

    /// Wheel kinematic parameters [m]:
    double wheel_separation_;
    double wheel_radius_;

    /// Previou wheel position/state [rad]:
    double left_wheel_old_pos_;
    double right_wheel_old_pos_;

    /// Rolling mean accumulators for the linar and angular velocities:
    size_t velocity_rolling_window_size_;
    RollingMeanAcc linear_acc_;
    RollingMeanAcc angular_acc_;

    /// Integration funcion, used to integrate the odometry:
    IntegrationFunction integrate_fun_;
  };
}

#endif /* ODOMETRY_H_ */

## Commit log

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2016-01-14 [add] 共通部分のxacroを追加
    [common.xacro, materials.xacro]
2016-01-15 [add] add cad data
    .dae (collada) data for visual
    .stl data for collision
    [base_link.stl, bogie_left_link.stl, bogie_right_link.stl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]
2016-01-18 [modify] cad datas
    [base_link.stl, bogie_left_link.stl, bogie_right_link.stl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]
2016-01-18 [add] xacro file for base_link
    [body.urdf.xacro]
2016-01-18 [add] xacro file for bogie and rocker
    [leg.urdf.xacro]
2016-01-18 [add] xacro file for wheel and support
    [wheel.urdf.xacro]
2016-01-18 [add] xacro file for whole body of robot
    [fr01.urdf.xacro, test.urdf]
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2016-01-19 [modify] modify stl and collada datas
    modify the positon and pose of origin frame
    modify the some textures (support_link and bogie_left_link)
    [rocker_left_link.stl, support_link.stl]
2016-01-19 [modify] modify the xacro files
    use the insert_block macros
    [fr01.urdf.xacro, leg.urdf.xacro, wheel.urdf.xacro]
2016-01-19 [add] add the urdf file from fr01.urdf.xacro file
    [fr01.urdf, test.urdf]
2016-01-19 [add] add xacro file for gazebo tags on body
    [body.gazebo.xacro, body.urdf.xacro]
2016-01-19 [add] add gazebo tag for leg
    [leg.gazebo.xacro]
2016-01-19 [add] add transmission tags for leg
    [leg.transmission.xacro]
2016-01-19 [add] include files for gazebo & transmission tag
    [leg.urdf.xacro]
2016-01-19 [add] add gazebo tags for wheel
    [wheel.gazebo.xacro]
2016-01-19 [add] add transmission tag for wheel
    [wheel.transmission.xacro]
2016-01-19 [add] include files for gazebo & transmission tags
    [wheel.urdf.xacro]
2016-01-19 [add] add gazebo & transmisson elements for whole
    [fr01.urdf.xacro]
2016-01-19 [rename] rename support_link to steer_link
    [fr01.urdf.xacro, steer_link.stl, wheel.gazebo.xacro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]
2016-01-19 [modify] regenerate fr01.urdf
    [fr01.urdf]
2016-01-19 [modify] modify the base_footprint height
    modify the height from base_footprint to base_link
    [fr01.urdf, fr01.urdf.xacro]
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2016-01-19 [modify] modify base_footprint
    On this robot, the base_link frame will move.
    So, If we want base_footprint frame(always on grand surface),
    we need to change the parent-child relationship.
    That is the parent of base_footprint is rocker_right_link.
    [fr01.urdf, fr01.urdf.xacro]
2016-01-19 [fix] modify actuator tags
    add actuator elements to get joint_states
    [leg.transmission.xacro]
2016-01-20 [WIP] add fr01_controller_node
    fr01_controller_node control wheel motor speed.
    Now, method of control is poor.
2016-01-20 add .ino file for arduino mega2560
    we use arduino mega2560 for motor control.
2016-01-20 add .gitignore file
    I used arduino-mk. If we build using arduino-mk, arduino-mk will make
    directory and generate object files into the directory.
2016-01-20 fix time stamp was not added
    I forgot to add time stamp, when publish.
    [fr01_controller.cpp]
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2016-01-20 change type of command to arduino.
    sensor_msgs::JointState -> Int32multiarray
    if i use sensor_msgs::JointState, it doesn't work well.
    i think the size of message that use sensor_msgs::JointState is over
    limitation of serial.
    [fr01_controller.cpp, source.ino]
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2016-01-20 fix calculataion about steering
    changed front of robot
2016-01-21 change using servo motor
    one of servo motors was broken. so i took a step.
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2016-01-21 fix not stopping when dont come /cmd_vel
    if /cmd_vel isnt subscribed, callback function isnt called.
    [fr01_controller.cpp]
2016-01-22 modified to take steps for /cmd_vel.
    I took steps for /cmd_vel problem(not update when no operating) in
    fr01_controller.
    But, I moved to fr01_driver.
    [fr01_controller.cpp]
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2016-02-03 fix wheel speed input and steer joint rotate
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2016-02-07 add hokuyo3d to xacro
    [fr01_with_hokuyo3d.urdf.xacro, hokuyo3d.urdf.xacro]
2016-02-07 fix hokuyo3d position and shape
    [fr01_with_hokuyo3d.urdf.xacro, hokuyo3d.urdf.xacro]
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2016-02-08 [Fix] rocker_right_link.daeの読み込みに関して，エラーが出ていたので出力し直しました．
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2016-02-09 fix calculation of steer angle
2016-02-09 fix calc steer angle in 4 steering mode
2016-02-15 [add] diff_drive_controller as a template
    [diffbot.xacro, diffbot_bad.xacro, diffbot_controllers.yaml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]
2016-02-18 [WIP] fix encoder count direction
2016-02-21 [modify] apply diff_drive_controller
    [fr01.urdf.xacro, wheel.transmission.xacro, wheel.urdf.xacro]
2016-02-21 [modify] changed the name of controller yaml file
    [fr01_controllers.yaml]
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2016-02-22 [WIP] removed namespace to activate diff_drive_controller
    [fr01.urdf.xacro, fr01_controllers.yaml, leg.urdf.xacro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]
2016-02-23 [fix] fixed joint configuration for diff_drive_controller
    [fr01.urdf.xacro, wheel.urdf.xacro]
2016-02-23 [modify] replace wheel params with xacro property
    [fr01.urdf.xacro, wheel.urdf.xacro]
2016-02-23 [modify] set back dynamics values of passive joints to its original ones.
    [leg.urdf.xacro]
2016-02-23 [remove] remove locally copied controller
    [diffbot.xacro, diffbot_bad.xacro, diffbot_controllers.yaml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]
2016-02-23 [modify] change controller to rocker_bogie_controller.
    [fr01_controllers.yaml]
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2016-02-27 [add] change controller name for spawner
    [fr01_controllers.yaml]
2016-02-29 [modify] add stabilized_base_link
    Added but it not works....omg
    [body.urdf.xacro, fr01.urdf.xacro]
2016-02-29 [modify] add base_stabilized
    It works on Gazebo.
    But, there are problem on TF tree...
    [body.gazebo.xacro, body.urdf.xacro, fr01.urdf.xacro]
2016-03-01 add transmission of base_link
    [body.transmission.xacro, body.urdf.xacro, fr01.urdf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]
2016-03-01 add controller for base_link_joint
    [body.urdf.xacro, fr01_controllers.yaml]
2016-03-01 [modify] remove position controller on base_link
    But I have no idea why the position controller on base_link_joint
    didn't work.
    [fr01_controllers.yaml]
2016-03-01 fix rotatable axis for base_link joint
    [fr01.urdf.xacro]
2016-03-02 modified base_frame_id and enabled odom tf
    [fr01_controllers.yaml]
2016-03-04 moved some files involved with ros_control to fr01_hw from fr01_driver
    see issue #18
    [b3m_driver.yaml, fr01_wheel_controller.cpp]
2016-03-08 [modify] enable odom on controller + add radius param.
    [fr01_controllers.yaml]
2016-03-13 [add]worked with gazebo
    [fr01_diff_drive_controller.yaml, fr01_rocker_bogie_controller.yaml]
2016-03-13 [add] rocker_bogie_controller
    [diffbot.xacro, diffbot_bad.xacro, diffbot_controllers.yaml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]
2016-03-13 [delete] deleted unnecessary files
    [diffbot.xacro, diffbot_bad.xacro, diffbot_controllers.yaml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]
2016-03-13 [modify] minor modification like comments
    [fr01_rocker_bogie_controller.yaml]
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2016-04-03 fixed problem of replacing joint state controller
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2016-05-27 fix joint state and tf problem
    First, /fr01_hardware_control node published /joint_states topic
    direcly. But, there was a problem that tf wasn't published correctly.
    Because, /fr01_hardware_control node published only wheel joint states
    and steer joint states. However, robot_state_publisher node who publish
    /tf require every /joint_states for all joint in order to publish proper
    /tf. So, I fixed.
2016-06-07 add hokuyo3d sensor to gazebo and visualize
    [body.urdf.xacro, fr01.urdf.xacro, fr01_with_hokuyo3d.urdf.xacro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]
2016-06-07 add dae file of hokuyo3d
    [hokuyo3d.urdf.xacro]
2016-06-07 changed robot model that with hokuyo sensor
    [fr01_with_hokuyo3d.urdf.xacro]
2016-06-07 fixed rotation of hokuyo3d
    [fr01_with_hokuyo3d.urdf.xacro]
2016-06-07 inversed hokuyo3d for tf
    [fr01_with_hokuyo3d.urdf.xacro, hokuyo3d.urdf.xacro]
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2016-06-09 add camera urdf
    [c930.urdf.xacro, fr01_with_sensors.urdf.xacro]
2016-06-09 add camera setting
    [c930-calib.yaml, c930.urdf.xacro, fr01_with_sensors.urdf.xacro]
2016-06-10 fix camera calib file path
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2016-11-22 make the camera disable
    [fr01_with_sensors.urdf.xacro]
